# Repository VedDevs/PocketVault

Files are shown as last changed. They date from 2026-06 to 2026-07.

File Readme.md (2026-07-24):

# PocketVault

A Password manager that fits in your pocket powered by the Seeed Studio XIAO RP2040.

---

## Features

- Offline password storage
- USB HID password typing
- OLED interface (Both 128x64 and 128x32 OLED's supported)
- Rotary encoder navigation
- No internet connection required
- Pocket-sized form factor

---

## Hardware

### Components

- Seeed Studio XIAO RP2040
- OLED Display (128×32 or 128×64)
- Rotary Encoder
- Custom PocketVault PCB
- 3D Printed Enclosure

---

## Firmware Features

### Current

- Project structure
- Menu system architecture
- Password vault structure
- Configurable display support

### Planned (Comming as soon as I get the Hardware!!)

- OLED UI
- Encoder input handling
- USB HID keyboard support
- Flash storage
- Master PIN lock screen
- Settings menu
- Password management

---
## PCB

This was my first PCB so please look carefully for problems (If you find some please email me).

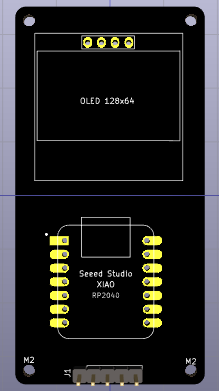
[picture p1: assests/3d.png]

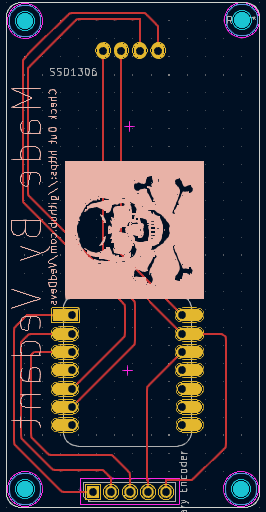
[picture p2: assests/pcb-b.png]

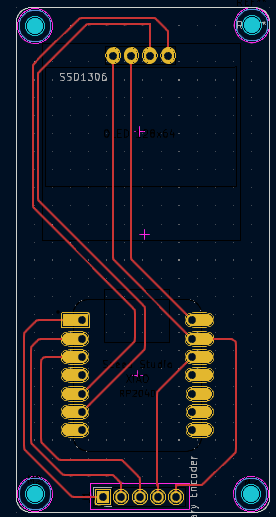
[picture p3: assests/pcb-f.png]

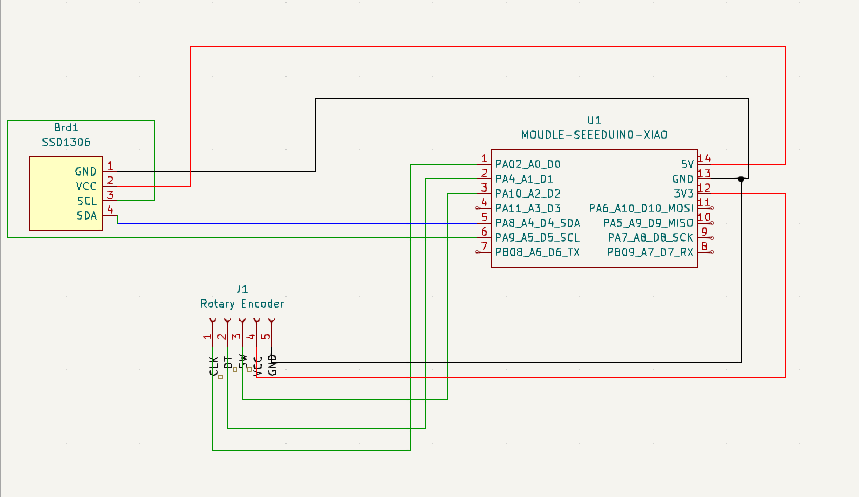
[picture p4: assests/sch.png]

---
## 3D enclosure 
It is in progress as I'm new to this skill
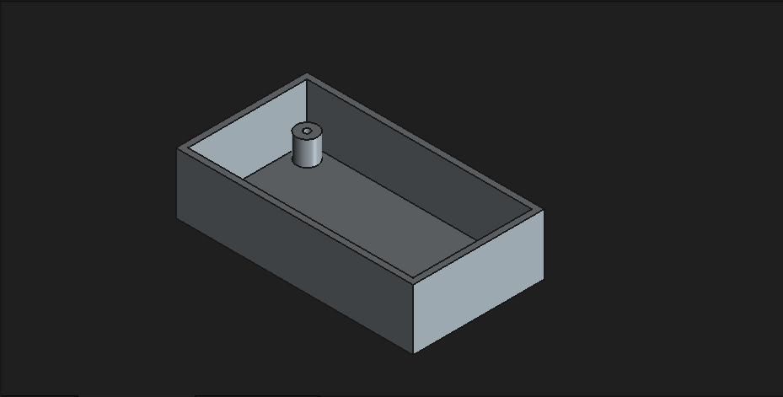
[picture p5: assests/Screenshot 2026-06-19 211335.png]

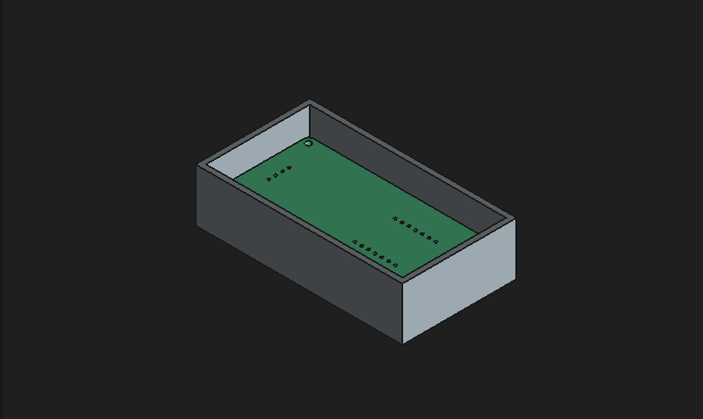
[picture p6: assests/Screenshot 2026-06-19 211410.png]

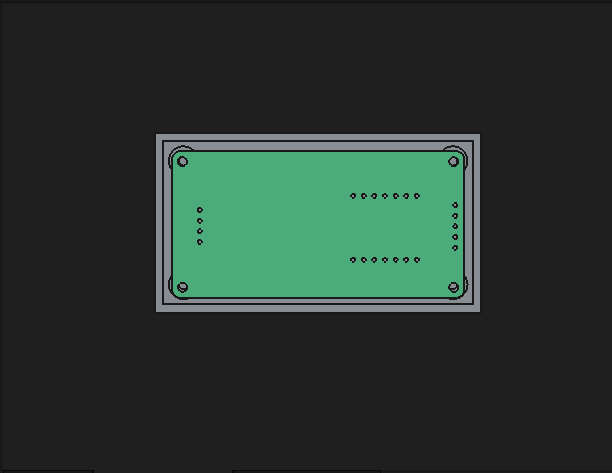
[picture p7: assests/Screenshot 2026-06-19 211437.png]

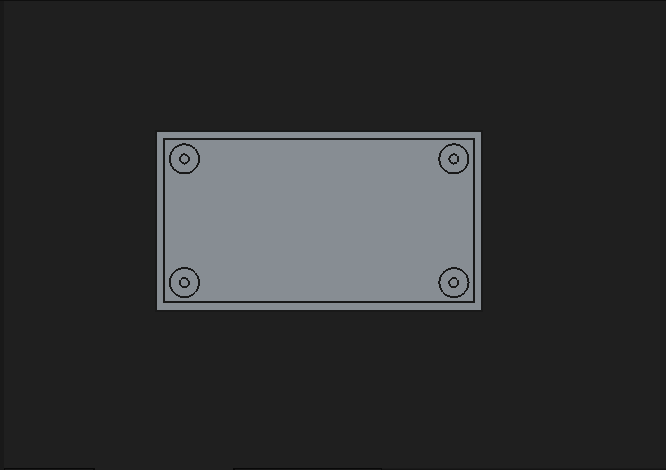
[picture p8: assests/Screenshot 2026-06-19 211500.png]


## Making it your Self

### Requirements

* Visual Studio Code
* PlatformIO Extension
* PCB (or make it your self using a perfboard)
* 3D printed Enclosure (or make it using sunboard)

### Clone

```bash
git clone https://github.com/VedDevs/PocketVault.git
cd PocketVault
```

### Build

```bash
pio run
```

### Upload

```bash
pio run -t upload
```

---

## Controls

| Action | Function |
| --- | --- |
| Rotate Encoder | Navigate Menu |
| Short Press | Select / Back |
| Long Press | Type Password |

---

## 0.91" OLED display Variant on Perfboard
0.91" Oled Model

---

## Contributing

Contributions & suggestions are welcome.

---
Made with ❤️ by Ved for StarDance

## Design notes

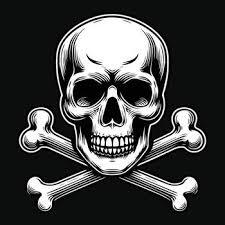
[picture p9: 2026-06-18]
PCB/images.jpg

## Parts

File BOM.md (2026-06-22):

# PocketVault BOM (Bill of Materials)

## Hardware Components

| Item | Qty | Description | Approx. Price (₹) |
|---|-----|---|---|
| Seeed Studio XIAO RP2040 | 1 | Main Microcontroller | 618 |
| SSD1306 OLED Display (128×64, I2C) | 1 | Display Module | 499 |
| SSD1306 OLED Display (128x32, I2C) | 1 | Display Module | 489 |
| ky-040 Rotary Encoder | 1 | Navigation Input | 131 |
| Perfboard | 1| Making meanwhile PCB | 121
| Pin Headers | -- | Connections | 100 |
| Total |||₹1970|

---
## Hardware Components (with PCB and Enlosure)
| Item | Qty | Description | Approx. Price (₹) |
|---|-----|---|---|
| Seeed Studio XIAO RP2040 | 1 | Main Microcontroller | 618 |
| SSD1306 OLED Display (128×64, I2C) | 1 | Display Module | 499 |
| ky-040 Rotary Encoder | 1 | Navigation Input | 131 |
| SSD1306 OLED Display (128x32, I2C) | 1 | Display Module | 489 |
| M2 Screws | 4 | Enclosure Assembly | 20 |
| Pin Headers | -- | Connections | 100 |
| 3D Printed Enclosure | 1 | Device Housing | 120 + Shipping |
| Custom PocketVault PCB | 1 | Main PCB | 100 |
| Total |||₹2077 + shipping|

---
## Estimated Cost

| Version | Estimated Cost(₹) | Estimated Cost($) as of 22/06/26|
|---|---|---|
| Perfboard Prototype | ₹1970 | $21
| Proper Prototype (With Enclosure Hardware) |₹2077 + shipping | $22 |

---
## Project Details
**Project:** PocketVault  
**Author:** Ved Devs

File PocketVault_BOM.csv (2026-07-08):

Section | Item | Qty | Description | ApproxPriceINR | Source
Perfboard Prototype | Seeed Studio XIAO RP2040 | 1 | Main Microcontroller | 618 | https://robu.in/product/seeed-studio-xiao-rp2040-v1-0/
Perfboard Prototype | SSD1306 OLED Display (128×64, I2C) | 1 | Display Module | 499 | https://amzn.in/d/0gyfDmF9
Perfboard Prototype | SSD1306 OLED Display (128×32, I2C) | 1 | Display Module | 489 | https://amzn.in/d/0gyfDmF9
Perfboard Prototype | KY-040 Rotary Encoder | 1 | Navigation Input | 131 | https://amzn.in/d/03GvdTSO
Perfboard Prototype | Perfboard | 1 | Making meanwhile PCB | 121 | https://amzn.in/d/05X3hMPs
Perfboard Prototype | Pin Headers | -- | Connections | 100 | https://amzn.in/d/0fD0QsFy
Perfboard Prototype | Total |  |  | 1960
Enclosure Prototype | Seeed Studio XIAO RP2040 | 1 | Main Microcontroller | 618 | https://robu.in/product/seeed-studio-xiao-rp2040-v1-0/
Enclosure Prototype | SSD1306 OLED Display (128×64, I2C) | 1 | Display Module | 499 | https://amzn.in/d/0gyfDmF9
Enclosure Prototype | KY-040 Rotary Encoder | 1 | Navigation Input | 131 | https://amzn.in/d/03GvdTSO
Enclosure Prototype | SSD1306 OLED Display (128×32, I2C) | 1 | Display Module | 489 | https://amzn.in/d/0gyfDmF9
Enclosure Prototype | M2 Screws | 4 | Enclosure Assembly | 20 | Local Vendors
Enclosure Prototype | Pin Headers | -- | Connections | 100 | https://amzn.in/d/0fD0QsFy
Enclosure Prototype | 3D Printed Enclosure | 1 | Device Housing | 120 + Shipping (Approx) | https://jlcpcb.com
Enclosure Prototype | Custom PocketVault PCB | 1 | Main PCB | 100 | https://jlcpcb.com
Enclosure Prototype | Total |  |  | 2099

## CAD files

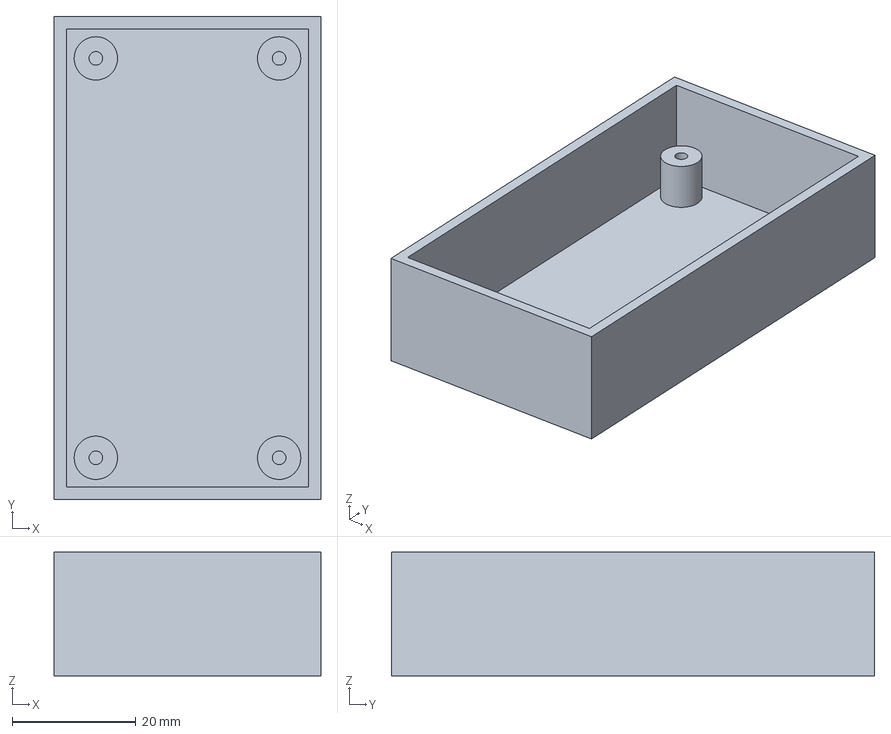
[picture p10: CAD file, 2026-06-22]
3D designs/3d design.FCStd
43.1 x 78.0 x 20.0 mm

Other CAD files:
3D designs/PocketVault.FCStd

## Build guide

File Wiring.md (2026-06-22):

# PocketVault Wiring

## Seeed Studio XIAO RP2040 Pinout
https://docs.zephyrproject.org/latest/boards/seeed/xiao_rp2040/doc/index.html

### OLED Display (SSD1306 I2C)

| OLED Pin | XIAO RP2040 Pin |
|---|---|
| VCC | 3V3 |
| GND | GND |
| SDA | D6 |
| SCL | D7 |

---

### Rotary Encoder

| Encoder Pin | XIAO RP2040 Pin |
|---|---|
| CLK | D2 |
| DT | D3 |
| SW | D4 |
| VCC | 3V3 |
| GND | GND |

---

## Wiring Diagram

```text
                PocketVault

         ┌─────────────────────┐
         │   XIAO RP2040       │
         │                     │
         │ D2 ───── CLK        │
         │ D3 ───── DT         │
         │ D4 ───── SW         │
         │                     │
         │ D6 ───── SDA        │
         │ D7 ───── SCL        │
         │                     │
         │ 3V3 ──── VCC        │
         │ GND ──── GND        │
         └─────────────────────┘
                  │
        ┌─────────┴─────────┐
        │                   │
   ┌─────────┐       ┌──────────┐
   │ OLED    │       │ Encoder  │
   │ SSD1306 │       │   EC11   │
   └─────────┘       └──────────┘
````

---

## Firmware Pin Definitions

```cpp
#define ENCODER_CLK 2
#define ENCODER_DT  3
#define ENCODER_SW  4

#define OLED_SDA    6
#define OLED_SCL    7
```

---

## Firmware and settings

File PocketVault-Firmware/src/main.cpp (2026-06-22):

/*
Project Name : PocketVault
Author : Vedant

Made for StarDance with ♥
*/

// inclusiuons
#include <Arduino.h>
#include "config.h"
#include "vault.h"
#include "setting.h"

// Global Variables
enum ScreenState
{
  MENU,
  ENTRY_VIEW,
  SETTINGS,
  LOCK_SCREEN
};
ScreenState currentScreen = MENU;

int selectedItem = 0;
int CurrentEntry = 0;

// UI Functions
void moveUp()
{
  if (selectedItem > 0)
  {
    selectedItem--;
  }
  if (selectedItem < 0)
    selectedItem = VAULT_SIZE - 1;
}
void moveDown()
{
  if (selectedItem < VAULT_SIZE - 1)
  {
    selectedItem++;
  }
  if (selectedItem >= VAULT_SIZE)
    selectedItem = 0;
}
void selectItem()
{
  CurrentEntry = selectedItem;
  currentScreen = ENTRY_VIEW;
}
void goBack()
{
  currentScreen = MENU;
}

// Simulate with Serial Monitor (Allows you simulate the menu in a serial moniotor)
void drawMenu()
{
  Serial.println();

  if (currentScreen == MENU)
  {
    Serial.println("=== PocketVault ===");
    for (int i = 0; i < VAULT_SIZE; i++)
    {
      if (i == selectedItem)
      {
        Serial.print("> ");
      }
      else
      {
        Serial.print("  ");
      }
      Serial.println(vault[i].title);
    }
  }
  else
  {
    Serial.println("===Entry===");
    Serial.println(vault[CurrentEntry].title);
    Serial.println();
    Serial.println("Hold = Enter");
    Serial.println("Press = Back");
  }
}

void setup()
{
  Serial.begin(115200);
  Serial.println("PocketVault starting up...");

  // Simulation Purposes Only == DO NOT UNCOMMENT
  drawMenu();

  moveDown();
  drawMenu();

  moveUp();
  drawMenu();
  
  goBack();
  drawMenu();
}
void loop()
{
  // put your main code here, to run repeatedly:
}

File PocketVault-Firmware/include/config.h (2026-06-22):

#pragma once

// define your screen type here
#define DISPLAY_128x64

// Or uncomment the following line to use a 128x32 display instead
// #define DISPLAY_128x32

// define your rotary encoder pins here
#define ENCODER_CLK 2
#define ENCODER_DT 3
#define ENCODER_SW 4

// Define your OLED display pins here
#define OLED_SDA 6
#define OLED_SCL 7

// Define the long press duration for the rotary encoder button (in milliseconds)
#define LONG_PRESS_TIME 1000

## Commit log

2026-07-08 Update total count in BOM file
    Updated total count in PocketVault_BOM.csv.
    [PocketVault_BOM.csv]
2026-07-08 Fix formatting in PocketVault_BOM.csv
    [PocketVault_BOM.csv]
2026-07-08 Add source links to PocketVault BOM items
    Added source URLs for components in the BOM.
    [PocketVault_BOM.csv]
2026-07-08 Fix total line formatting in BOM CSV
    [PocketVault_BOM.csv]
2026-07-08 Fix URLs and formatting in PocketVault_BOM.csv
    Updated the PocketVault BOM with corrected URLs and formatting.
    [PocketVault_BOM.csv]
2026-07-08 Adjust total costs in PocketVault BOM
    Updated total costs for both prototypes in BOM.
    [PocketVault_BOM.csv]
